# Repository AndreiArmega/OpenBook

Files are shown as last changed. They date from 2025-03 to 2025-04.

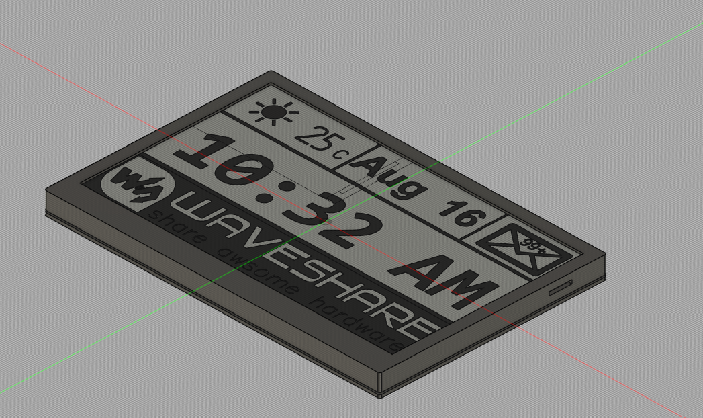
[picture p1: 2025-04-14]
Images/Screenshot 2025-04-14 231651.png

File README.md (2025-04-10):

# OpenBook
## Diagrama bloc
Diagram

## Bill of Materials
| Device | Datasheet | Purchase |
|---|---|---|
| 112A-TAAR-R03_ATTEND | [Datasheet](https://www.attend.com.tw/data/download/file/112A-TAAR-R03_Spec.pdf) | [Purchase](https://www.digikey.be/en/products/detail/attend-technology/112A-TAAR-R03/17633923) |
| ADAFRUIT_LEDCHIP-LED0603 | [Datasheet](https://www.mouser.com/datasheet/2/423/LSM0603472V_(1)-1379786.pdf) | [Purchase](https://grobotronics.com/led-0603-smd-blue.html?sl=en) |
| BD5229G-TR | [Datasheet](https://www.rohm.com/products/power-management/voltage-detectors/adjustable-delay-time/bd5229g-product) | [Purchase](https://eu.mouser.com/ProductDetail/ROHM-Semiconductor/BD5229G-TR?qs=4kLU8WoGk0vvnhrrYwdszw%3D%3D) |
| BUTTON_CUSYOMV1 | [Datasheet](https://www.mouser.com/datasheet/2/315/sw_lt_eng_smalls_side-1289033.pdf) | [Purchase](https://industry.panasonic.com/global/en/products/control/switch/light-touch/number/evqpuj02k) |
| CPH3225A | [Datasheet](https://ro.mouser.com/datasheet/2/360/Seiko_Instruments_MicroBattery_E_20230330_2024Jan_-3561061.pdf) | [Purchase](https://ro.mouser.com/ProductDetail/Seiko-Semiconductors/CPH3225A?qs=3etwrb1wR%252BhUOph6lAO7eg%3D%3D) |
| DS3231SN# | [Datasheet](https://ro.mouser.com/datasheet/2/609/DS3231-3421123.pdf) | [Purchase](https://ro.mouser.com/ProductDetail/Analog-Devices-Maxim-Integrated/DS3231SN?qs=1eQvB6Dk1vhUlr8%2FOrV0Fw%3D%3D) |
| EAGLE-LTSPICE_CC0402 | [Datasheet](https://ro.mouser.com/datasheet/2/447/UPY_GP_NP0_16V_to_50V_18-1730511.pdf) | [Purchase](https://ro.mouser.com/ProductDetail/YAGEO/CC0402CRNPO9BN6R8?qs=AgBp2OyFlx%2FJkIyOSG1YWg%3D%3D) |
| ESP32-WROVER_AVX | [Datasheet](https://www.espressif.com/sites/default/files/documentation/esp32-wrover-e_esp32-wrover-ie_datasheet_en.pdf) | [Purchase](https://www.espressif.com/en/products/modules) |
| ESP32_WROVER_BME680_BME680 | [Datasheet](https://www.bosch-sensortec.com/media/boschsensortec/downloads/datasheets/bst-bme680-ds001.pdf) | [Purchase](https://www.optimusdigital.ro/en/temperature-sensors/4468-adafruit-bme680-temperature-humidity-pressure-and-gas-sensor.html) |
| ESP32_WROVER_EAGLE-LTSPICE_RR0402 | [Datasheet](https://www.espressif.com/sites/default/files/documentation/esp32-wrover-b_datasheet_en.pdf) | [Purchase](https://hr.mouser.com/ProductDetail/Espressif-Systems/ESP32-WROVER-E-N16R8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) |
| ESP32_WROVER_SPARKFUN-DISCRETESEMI_MOSFET_PCH-DMG2305UX-7 | [Datasheet](https://www.diodes.com/assets/Datasheets/DMG2305UX.pdf) | [Purchase](https://ro.mouser.com/ProductDetail/Diodes-Incorporated/DMG2305UX-7?qs=L1DZKBg7t5F%2FNBHrjfxC%252Bg%3D%3D) |
| ESP32_WROVER_SPARKFUN-IC-POWER_MCP73831 | [Datasheet](https://cdn.sparkfun.com/assets/learn_tutorials/6/9/5/MCP738312.pdf) | [Purchase](https://www.amazon.com/SparkFun-MicroMod-Main-Board-Built/dp/B0CD3D1V8J) |
| ESP32-C6-WROOM-1-N8 | [Datasheet](https://www.espressif.com/sites/default/files/documentation/esp32-c6-wroom-1_wroom-1u_datasheet_en.pdf) | [Purchase](https://www.digikey.com/en/products/detail/espressif/ESP32-C6-WROOM/2271115) |
| ESP32C6_VARISTORCN1812 | [Datasheet](https://www.alldatasheet.com/view.jsp?Searchword=CN1812) | [Purchase](https://www.digikey.com/en/products/base-product/epcos-tdk-electronics/495/CN1812/678185) |
| FH34SRJ-24S-0.5SH_99 | [Datasheet](https://ro.mouser.com/datasheet/2/185/FH34SRJ_24S_0_5SH_99__CL0580_1255_6_99_2DDrawing_0-1615044.pdf) | [Purchase](https://www.hirose.com/en/product/global-stock-information/CL0580-1255-6-99) |
| MAX17048G+T10 | [Datasheet](https://eu.mouser.com/datasheet/2/609/MAX17048_MAX17049-3469099.pdf) | [Purchase](https://eu.mouser.com/ProductDetail/Analog-Devices-Maxim-Integrated/MAX17048G+T10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) |
| MBR0530 | [Datasheet](https://eu.mouser.com/datasheet/2/308/MBR0530_D-1810985.pdf) | [Purchase](https://eu.mouser.com/ProductDetail/onsemi-Fairchild/MBR0530?qs=VOMQJJE%252BBNniwJKcE3T43Q%3D%3D) |
| MCP73831 | [Datasheet](https://ww1.microchip.com/downloads/en/DeviceDoc/MCP73831-Family-Data-Sheet-DS20001984H.pdf) | [Purchase](https://www.microchip.com/en-us/product/mcp73831) |
| PGB1010603MR | [Datasheet](https://www.littelfuse.com/assetdocs/pulseguard-esd-suppressors-pgb1-datasheet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) | [Purchase](https://ro.mouser.com/ProductDetail/Littelfuse/PGB1010603MR?qs=gu7KAQ731URLg4GSnNNN7Q%3D%3D) |
| QWIIC_CONNECTORJS-1MM | [Datasheet](https://eu.mouser.com/datasheet/2/813/Qwiic_Connector_Datasheet-1223982.pdf) | [Purchase](https://eu.mouser.com/ProductDetail/SparkFun/PRT-14417?qs=wd5RIQLrsJhgdz%2FpmZ%2F3GQ%3D%3D) |
| RCL_CPOL-EUCT3528 | [Datasheet](https://www.rcl.com/datasheet/CPOL-EUCT3528.pdf) | [Purchase](https://www.rcl.com/purchase/CPOL-EUCT3528) |
| SAMACSYS_PARTS_USB4110-GF-A | [Datasheet](https://ro.mouser.com/datasheet/2/837/GCT_USB4110_Product_Drawing___20k_cycles-3455479.pdf) | [Purchase](https://ro.mouser.com/ProductDetail/GCT/USB4110-GF-A?qs=KUoIvG%2F9IlYiZvIXQjyJeA%3D%3D) |
| SI1308EDL-T1-GE3 | [Datasheet](https://www.vishay.com/docs/63399/si1308edl.pdf) | [Purchase](https://eu.mouser.com/ProductDetail/Vishay-Semiconductors/SI1308EDL-T1-GE3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) |
| Solder Jumper | [Datasheet](https://multimedia.3m.com/mws/media/117314O/3m-bumpon-protective-products-molded-shapes-colored-and-clear.pdf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) | [Purchase](https://www.digikey.ro/ro/products/detail/3m/SJ-5007-BLACK/102599) |
| TPTP20R | [Datasheet ](https://all-industrial-shop.com/catalog/misumi/id1304817_a-tptp20-10-4001-p05-199001) | [Purchase](https://all-industrial-shop.com/catalog/misumi/id1304817_a-tptp20-10-4001-p05-199001) |
| USBLC6-2SC6Y | [Datasheet](https://eu.mouser.com/datasheet/2/389/usblc6_2sc6y-1852505.pdf) | [Purchase](https://eu.mouser.com/ProductDetail/STMicroelectronics/USBLC6-2SC6Y?qs=gNDSiZmRJS%2FOgDexvXkdow%3D%3D)  |
| W25Q512JVEIQ | [Datasheet](https://eu.mouser.com/datasheet/2/949/Winbond_W25Q512JV_Datasheet-3240039.pdf) | [Purchase](https://eu.mouser.com/ProductDetail/Winbond/W25Q512JVEIQ?qs=l7cgNqFNU1jw6svr3at6tA%3D%3D) |
| XC6220A331MR-G | [Datasheet](https://eu.mouser.com/datasheet/2/760/xc6220-3371556.pdf) | [Purchase](https://eu.mouser.com/ProductDetail/Torex-Semiconductor/XC6220A331MR-G?qs=AsjdqWjXhJ8ZSWznL1J0gg%3D%3D) |

## Functionality
### ESP32-C6-WROOM-1-N8
The ESP32-C6-WROOM-1-N8 is a powerful microcontroller module from Espressif Systems that integrates Wi-Fi (802.11ax) and Bluetooth LE (5.0) capabilities. It is designed for IoT (Internet of Things) applications that require wireless communication. Let's focus on how the components interact with this microcontroller, as well as consider interfaces, communication specifications, energy consumption, and processing:

### Key Components That Interact with the ESP32-C6-WROOM-1-N8:
  1. MCP73831 - Battery Charge Management IC
  Interface: This component connects to the ESP32-C6 via GPIO pins to monitor battery status and control the charging process.
  
  Functionality: The MCP73831 manages the charging of lithium-ion batteries. It interacts with the ESP32 for real-time battery monitoring. The ESP32 can detect charging states or battery levels through ADC (Analog-to-Digital Converter) readings or dedicated communication (e.g., I2C/SPI) if the design includes more advanced battery management.
  
  Power Consumption: The ESP32-C6-WROOM-1-N8 would use this component to ensure efficient power management, especially when operating on a battery.
  
  2. ESP32-WROVER (e.g., ESP32-WROVER-BME680) - Environmental Sensing
  Interface: The ESP32 connects to the BME680 sensor via I2C (or SPI) to read environmental data, such as temperature, humidity, pressure, and air quality.
  
  Functionality: The BME680 sensor communicates with the ESP32 via I2C/SPI, providing critical environmental data. This is commonly used in IoT applications like smart home systems, weather stations, or air quality monitoring systems.
  
  Power Consumption: The ESP32-C6 must manage the power consumption of the sensor and optimize wake-up intervals, using low-power states when idle.
  
  3. USBLC6-2SC6Y - USB Transient Voltage Suppressor
  Interface: This component is generally used on the USB lines connecting the ESP32 to external devices. It is connected across the USB data lines to prevent damage from voltage spikes.
  
  Functionality: It ensures that the USB port of the ESP32 is protected from over-voltage or transient spikes that could otherwise damage sensitive circuits.
  
  Power Consumption: USBLC6-2SC6Y does not significantly affect power consumption, but it ensures stable power delivery to the microcontroller.
  
  4. DS3231SN# - Real-Time Clock (RTC)
  Interface: I2C is used to connect the DS3231SN# RTC module with the ESP32.
  
  Functionality: The DS3231 provides accurate timekeeping, even when the ESP32 is powered down. This is important for time-dependent tasks, like logging data, scheduling actions, or maintaining time in low-power states.
  
  Power Consumption: The ESP32 can operate in deep sleep mode, while the DS3231 keeps track of time. The RTC has low power consumption and runs off a small coin cell battery.
  
  5. W25Q512JVEIQ - Flash Memory
  Interface: This flash memory connects to the ESP32 via the SPI interface.
  
  Functionality: The W25Q512JVEIQ is used to store data, firmware, or other assets for the application. It is commonly used for data logging, firmware updates, or storing non-volatile data.
  
  Power Consumption: Flash memory is typically low power, but the ESP32 should manage read/write operations carefully to conserve energy, especially when operating on battery power.
  
  6. PGB1010603MR - ESD Protection
  Interface: This component is placed on various I/O lines of the ESP32 (such as GPIO, SPI, I2C, etc.) to protect against electrostatic discharge.
  
  Functionality: PGB1010603MR protects the ESP32 from ESD, preventing damage from static electricity that could occur during handling or operation.
  
  Power Consumption: It does not impact the power consumption of the ESP32, but it is crucial for ensuring stable operation in environments with potential ESD risk.

### Communication Interfaces & Specifications:
Wireless Communication: The ESP32-C6-WROOM-1-N8 supports Wi-Fi 6 (802.11ax) and Bluetooth 5.0. These are high-speed communication protocols for connecting to IoT devices, networks, and other wireless systems.

Wi-Fi: 2.4GHz and 5GHz bands support high-speed data transfer.

Bluetooth LE: Allows for low-power, short-range communication with peripherals.

Wired Communication: The microcontroller supports multiple communication protocols, such as:

SPI: Used for high-speed communication with peripherals like flash memory (W25Q512JVEIQ).

I2C: A popular protocol for sensors like the BME680 and the DS3231.

UART: For serial communication, commonly used for debugging or communication with external devices.

### Processing Power & Energy Consumption:
  Processing: The ESP32-C6 has a single-core 32-bit RISC-V processor with a clock speed of up to 160 MHz. It is optimized for real-time processing and is capable of handling multi-tasking and communication protocols like Wi-Fi and Bluetooth simultaneously.
  
  Energy Consumption: The ESP32-C6-WROOM-1-N8 is designed for low-power applications. It features various low-power modes such as:
  
  Light Sleep: Keeps the Wi-Fi/Bluetooth active while reducing CPU activity.
  
  Deep Sleep: Cuts off most peripherals and uses minimal power.
  
  Hibernation: The lowest power mode, where only the RTC is active (useful for low-power sensors or battery-powered IoT devices).
  
  Power Management: When integrated with components like the MCP73831 for battery charging and the DS3231SN# RTC, the ESP32-C6 can be configured to wake up at specific intervals to process tasks (e.g., checking sensors, reporting data) and return to sleep mode to conserve battery life.

## ESP32-C6 Pins

| **Pin ESP32** | **Funcție Principală** | **Componentă Conectată / Scop** |
|---|---|---|
| IO0 | INT_RTC | U3 (DNS323, Interrupt from RTC) – Triggering or controlling RTC operations. |
| IO1 | 32KHZ | U3 (DNS323, 32kHz Crystal Oscillator) – Used for timing and clock generation. |
| IO2 | MISO | J4 (112A-TAAR) & U1 (W25Q, SPI Data In) – Master In Slave Out line for SPI communication. |
| IO3 | EPD_BUSY | J1 (FH34, EPD busy signal) – Indicates when the EPD is busy. |
| IO4 | SS_SD | J4 (112A-TAAR, SD card chip select) – Controls SD card communication. |
| IO5 | EPD_DC | J1 (FH34, EPD Data/Command signal) – Controls the data or command mode for the EPD. |
| IO6 | SPI SCK | J1 (FH34) & U1 (W25Q, SPI Clock) – Provides clock signal for SPI communication. |
| IO7 | SPI MOSI | J4 (112A-TAAR), J1 (FH34), U1 (W25Q, SPI Data Out) – Master Out Slave In line for SPI communication. |
| IO8 | GPIO8 | 3V3 – Used as a general-purpose I/O pin, connected to 3.3V for simple logic. |
| IO9 | IO/BOOT | IC1 (BD5229) – Used for bootloading during startup. |
| IO10 | GPIO / SPI EPD CS | J1 (FH34, EPD Chip Select) – Selects EPD for SPI communication. |
| IO11 | GPIO / SPI FLASH CS | U1 (W25Q, Flash Chip Select) – Selects the flash memory for SPI communication. |
| IO12 | USB D | D1 (USBLC6, USB Data -) – Handles negative signal of USB communication. |
| IO13 | USB D+ | D1 (USBLC6, USB Data +) – Handles positive signal of USB communication. |
| IO15 | I/O CHANGE | IC1 (BD5229) – Used for triggering I/O state changes or controlling other circuits. |
| GPIO16 | TX | SPI TX – Transmit data via SPI for various components. |
| GPIO17 | RX | SPI RX – Receive data via SPI for various components. |
| IO18 | RTC_RST | U3 (DNS323, RTC Reset) – Reset signal for RTC operations. |
| IO19 | I2C SDA | IC2 (MCP73831, RTC SDA), IC3 (BME680, BME SDA/SDO) – I2C data line. |
| IO20 | EPD_3V3_c | Q2 (Voltage regulator) – Provides 3.3V to the EPD. |
| IO21 | SDA | J3 (Qwiic Connector), U3 (DNS323), BME680 (Sensor SDA), U4 (Max17048, SDA) – I2C data line for communication. |
| IO22 | SCL | J3 (Qwiic Connector), U3 (DNS323), BME680 (Sensor SCL), U4 (Max17048, SCL) – I2C clock line for communication. |
| IO23 | EPD_RST | J1 (FH34, EPD Reset) – Resets the EPD during initialization. |
| EN | RESET | Pull-up to 3.3V – Used to reset the ESP32-C6 module. |
| VDD | 3V3 | 3.3V Power supply for the module. |
| GND | GND | Ground connection. |
| NC | - | Not connected – Reserved pin. |

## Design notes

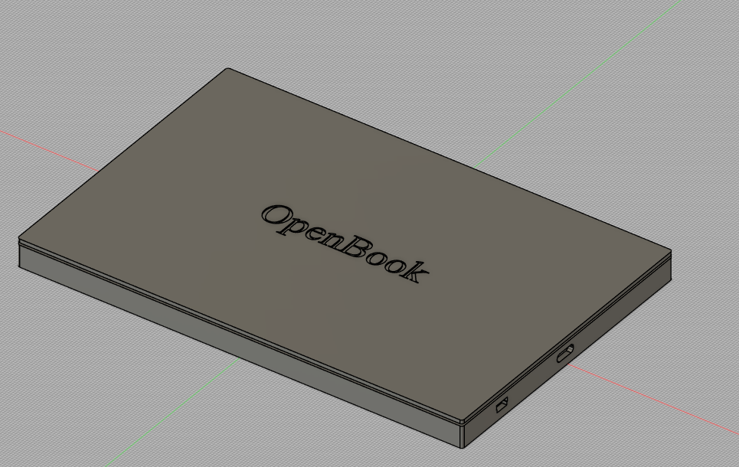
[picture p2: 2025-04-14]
Images/Screenshot 2025-04-14 231531.png

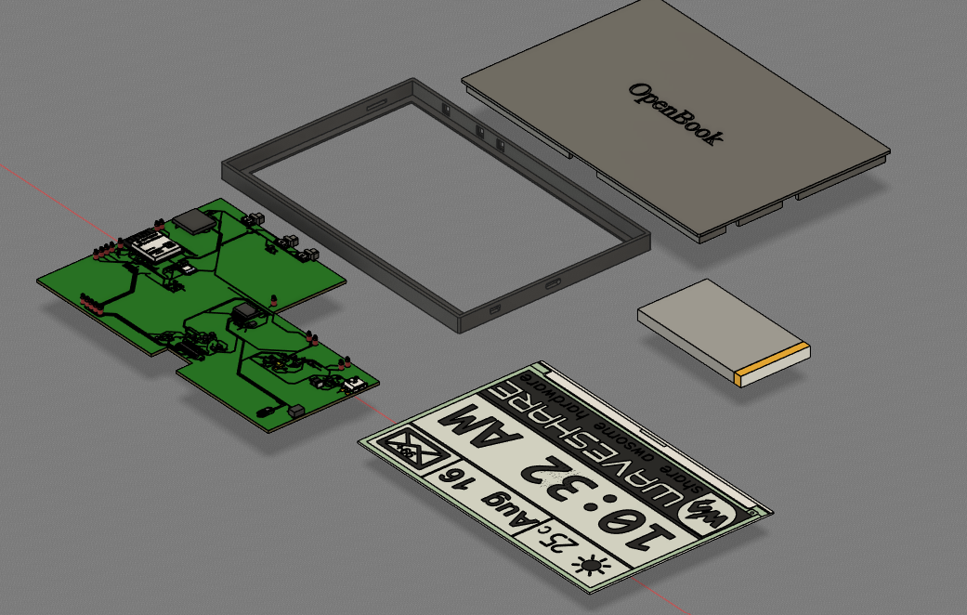
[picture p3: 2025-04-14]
Images/Screenshot 2025-04-14 232221.png

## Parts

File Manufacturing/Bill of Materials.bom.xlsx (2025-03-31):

Qty | Value | Device | Package | Parts | Description | ARROW_PART_NUMBER | ARROW_PRICE-STOCK | AVAILABILITY | CENTROID_NOT_SPECIFIED | CHECK_PRICES | COPYRIGHT | DATASHEET | DESCRIPTION | DIGIKEY_DESCRIPTION | DIGIKEY_PART_NUMBER | HEIGHT | LEAD_FREE | MANUFACTURER_NAME | MANUFACTURER_PART_NUMBER | MF | MFR_NAME | MOUSER_PART_NUMBER | MOUSER_PRICE-STOCK | MOUSER_TESTING_PART_NUMBER | MOUSER_TESTING_PRICE-STOCK | MP | MPN | PACKAGE | POPULARITY | PREFIX | PRICE | PROD_ID | PURCHASE-URL | ROHS | SNAPEDA_LINK | SPICEMODEL | SPICEPREFIX | TEMPERATURE_RANGE_HIGH | TEMPERATURE_RANGE_LOW | TP_SIGNAL_NAME | VALUE
1 |  | ADAFRUIT_LEDCHIP-LED0603 | ADAFRUIT_CHIP-LED0603 | CHG_LED | LED
1 |  | SJ | SJ | SJ1 | SMD solder JUMPER |  |  |  |  |  |  |  |  |  |  |  |  |  |  |  |  |  |  |  |  |  |  |  | 3
1 | 0.1uF/50V | ESP32_WROVER_EAGLE-LTSPICE_CC0402 | ESP32_WROVER_EAGLE-LTSPICE_C0402 | EPD_C5 | CAPACITOR, European symbol |  |  |  |  |  |  |  |  |  |  |  |  |  |  |  |  |  |  |  |  |  |  |  |  |  |  |  |  |  |  | NONE | C
1 | 0.47 | ESP32_WROVER_EAGLE-LTSPICE_RR0402 | ESP32_WROVER_EAGLE-LTSPICE_R0402 | R3 | RESISTOR, European symbol |  |  |  |  |  |  |  |  |  |  |  |  |  |  |  |  |  |  |  |  |  |  |  |  |  |  |  |  |  |  | NONE | R
1 | 100k | ESP32_WROVER_EAGLE-LTSPICE_RR0402 | ESP32_WROVER_EAGLE-LTSPICE_R0402 | R1_PWRUSB | RESISTOR, European symbol |  |  |  |  |  |  |  |  |  |  |  |  |  |  |  |  |  |  |  |  |  |  |  |  |  |  |  |  |  |  | NONE | R
5 | 100nF | EAGLE-LTSPICE_CC0402 | ESP32_WROVER_EAGLE-LTSPICE_C0402 | C6, C8, C9, C10, C_DELAY | CAPACITOR, European symbol |  |  |  |  |  |  |  |  |  |  |  |  |  |  |  |  |  |  |  |  |  |  |  |  |  |  |  |  |  |  | NONE | C
3 | 100nF | ESP32_WROVER_EAGLE-LTSPICE_CC0402 | ESP32_WROVER_EAGLE-LTSPICE_C0402 | C1, C2, C4_USB | CAPACITOR, European symbol |  |  |  |  |  |  |  |  |  |  |  |  |  |  |  |  |  |  |  |  |  |  |  |  |  |  |  |  |  |  | NONE | C
1 | 100uF | RCL_CPOL-EUCT3528 | RCL_CT3528 | C3 | POLARIZED CAPACITOR, European symbol |  |  |  |  |  |  |  |  |  |  |  |  |  |  |  |  |  |  |  |  |  |  |  | 0 |  |  |  |  |  |  |  | C
1 | 10K | ESP32_WROVER_EAGLE-LTSPICE_RR0402 | ESP32_WROVER_EAGLE-LTSPICE_R0402 | R_CL1 | RESISTOR, European symbol |  |  |  |  |  |  |  |  |  |  |  |  |  |  |  |  |  |  |  |  |  |  |  |  |  |  |  |  |  |  | NONE | R
15 | 10k | ESP32_WROVER_EAGLE-LTSPICE_RR0402 | ESP32_WROVER_EAGLE-LTSPICE_R0402 | R1, R1_PINH, R1_PINH1, R2-PINH, R2-PINH1, R4, R5, R6, R7, R8, R9, R10, R_BOOT, R_CHANGE, R_RESET | RESISTOR, European symbol |  |  |  |  |  |  |  |  |  |  |  |  |  |  |  |  |  |  |  |  |  |  |  |  |  |  |  |  |  |  | NONE | R
1 | 10uF | ESP32_WROVER_EAGLE-LTSPICE_CC0402 | ESP32_WROVER_EAGLE-LTSPICE_C0402 | C7 | CAPACITOR, European symbol |  |  |  |  |  |  |  |  |  |  |  |  |  |  |  |  |  |  |  |  |  |  |  |  |  |  |  |  |  |  | NONE | C
1 | 112A-TAAR-R03_ATTEND | 112A-TAAR-R03_ATTEND | 112ATAARR03ATTEND | J4 | Micro SD Card Socket, Push-Push Type, Top Mount, SMT, H=1.83mm, 10u |  |  |  |  |  |  |  | Micro SD Card Socket | Push-Push Type | Top Mount | SMT | H=1.83mm | 10u |  |  | 1.9mm |  | ATTEND | 112A-TAAR-R03 ATTEND
1 | 15 | ESP32_WROVER_EAGLE-LTSPICE_RR0402 | ESP32_WROVER_EAGLE-LTSPICE_R0402 | R_CAPACITOR | RESISTOR, European symbol |  |  |  |  |  |  |  |  |  |  |  |  |  |  |  |  |  |  |  |  |  |  |  |  |  |  |  |  |  |  | NONE | R
1 | 1uF | EAGLE-LTSPICE_CC0402 | ESP32_WROVER_EAGLE-LTSPICE_C0402 | C5 | CAPACITOR, European symbol |  |  |  |  |  |  |  |  |  |  |  |  |  |  |  |  |  |  |  |  |  |  |  |  |  |  |  |  |  |  | NONE | C
9 | 1uF/50V | ESP32_WROVER_EAGLE-LTSPICE_CC0402 | ESP32_WROVER_EAGLE-LTSPICE_C0402 | EPD_C1, EPD_C2, EPD_C6, EPD_C7, EPD_C8, EPD_C9, EPD_C10, EPD_C11, EPD_C12 | CAPACITOR, European symbol |  |  |  |  |  |  |  |  |  |  |  |  |  |  |  |  |  |  |  |  |  |  |  |  |  |  |  |  |  |  | NONE | C
1 | 2.2 | ESP32_WROVER_EAGLE-LTSPICE_RR0402 | ESP32_WROVER_EAGLE-LTSPICE_R0402 | R2 | RESISTOR, European symbol |  |  |  |  |  |  |  |  |  |  |  |  |  |  |  |  |  |  |  |  |  |  |  |  |  |  |  |  |  |  | NONE | R
1 | 200 | ESP32_WROVER_EAGLE-LTSPICE_RR0402 | ESP32_WROVER_EAGLE-LTSPICE_R0402 | R1_BAT | RESISTOR, European symbol |  |  |  |  |  |  |  |  |  |  |  |  |  |  |  |  |  |  |  |  |  |  |  |  |  |  |  |  |  |  | NONE | R
2 | 20V/4.2A/52mO/1.4W | ESP32_WROVER_SPARKFUN-DISCRETESEMI_MOSFET_PCH-DMG2305UX-7 | ESP32_WROVER_SPARKFUN-DISCRETESEMI_SOT23-3 | Q1, Q2 | P-channel MOSFETs |  |  |  |  |  |  |  |  |  |  |  |  |  |  |  |  |  |  |  |  |  |  |  |  |  |  | TRAN-14388 |  |  |  |  |  |  |  |  | 20V/4.2A/52mO/1.4W
1 | 2k | ESP32_WROVER_EAGLE-LTSPICE_RR0402 | ESP32_WROVER_EAGLE-LTSPICE_R0402 | R2_BAT | RESISTOR, European symbol |  |  |  |  |  |  |  |  |  |  |  |  |  |  |  |  |  |  |  |  |  |  |  |  |  |  |  |  |  |  | NONE | R
5 | 4.7uF | ESP32_WROVER_EAGLE-LTSPICE_CC0402 | ESP32_WROVER_EAGLE-LTSPICE_C0402 | C1_BAT, C1_BAT1, C1_BAT2, C2_BAT, C5_USB | CAPACITOR, European symbol |  |  |  |  |  |  |  |  |  |  |  |  |  |  |  |  |  |  |  |  |  |  |  |  |  |  |  |  |  |  | NONE | C
1 | 4.7uF/25V | ESP32_WROVER_EAGLE-LTSPICE_CC0402 | ESP32_WROVER_EAGLE-LTSPICE_C0402 | C4 | CAPACITOR, European symbol |  |  |  |  |  |  |  |  |  |  |  |  |  |  |  |  |  |  |  |  |  |  |  |  |  |  |  |  |  |  | NONE | C
2 | 5k1 | ESP32_WROVER_EAGLE-LTSPICE_RR0402 | ESP32_WROVER_EAGLE-LTSPICE_R0402 | R2-USB, R2-USB1 | RESISTOR, European symbol |  |  |  |  |  |  |  |  |  |  |  |  |  |  |  |  |  |  |  |  |  |  |  |  |  |  |  |  |  |  | NONE | R
1 | 68uH | 744043680IND_4828-WE-TPC_WRE | IND_4828-WE-TPC_WRE | L1 |  |  |  |  |  |  | Copyright (C) 2024 Ultra Librarian. All rights reserved. |  |  |  |  |  |  |  | 744043680 |  | Wurth Electronics
1 | BD5229G-TR | BD5229G-TR | SOT95P280X125-5N | IC1 | Voltage Detector with Adjustable Delay Time: CMOS processes are utilized to develop high precision, low current consumption CMOS reset ICs that allow arbitrary setting of the delay time. The extensive lineup includes both Nch Open Drain and CMOS output types in a wide range of detection voltages (from 2.3V to 6.0V, in 0.1V steps), enabling selection of the ideal solution based on customer requirements. In addition, the entire series is of course both lead-free and RoHS-compliant. |  |  |  |  |  |  |  | Voltage Detector with Adjustable Delay Time: CMOS processes are utilized to develop high precision | low current consumption CMOS reset ICs that allow arbitrary setting of the delay time. The extensive lineup includes both Nch Open Drain and CMOS output types in a wide range of detection voltages (from 2.3V to 6.0V | in 0.1V steps) | enabling selection of the ideal solution based on customer requirements. In addition | the entire series is of course both lead-free and RoHS-compliant. |  |  | 1.25mm |  | ROHM Semiconductor | BD5229G-TR |  |  | 755-BD5229G-TR | https://www.mouser.co.uk/ProductDetail/ROHM-Semiconductor/BD5229G-TR?qs=4kLU8WoGk0vvnhrrYwdszw%3D%3D
3 | BUTTON_CUSYOMV1 | BUTTON_CUSYOMV1 | MYBUTTON | BUT1, BUT2, BUT3
1 | CPH3225A | CPH3225A | CAPCP3225X100N | C10_SUPERCAP | Cap 0.011F 3.3V 1210 Flat Check availability |  |  | Not in stock |  | https://www.snapeda.com/parts/CPH3225A/Seiko+Instruments/view-part/?ref=eda |  |  | 11 mF (EDLC) Supercapacitor 3.3 V 1210 (3225 Metric) - - |  |  |  |  |  |  | Seiko Instruments |  |  |  |  |  | CPH3225A |  | 1210 Seiko |  |  | None |  | https://www.snapeda.com/api/url_track_click_mouser/?unipart_id=562593&manufacturer=Seiko Instruments&part_name=CPH3225A&search_term=None |  | https://www.snapeda.com/parts/CPH3225A/Seiko+Instruments/view-part/?ref=snap
1 | DS3231SN# | DS3231SN# | SOIC127P1032X265-16N | U3 | Real Time Clock Serial 16-Pin SOIC W T/R Check availability |  |  | In Stock |  | https://www.snapeda.com/parts/DS3231SN%23/Analog+Devices/view-part/?ref=eda |  |  | Extremely Accurate I²C-Integrated RTC/TCXO/Crystal |  |  |  |  |  |  | Analog Devices |  |  |  |  |  | DS3231SN# |  | SOIC-16 Maxim |  |  | None |  | https://www.snapeda.com/api/url_track_click_mouser/?unipart_id=99048&manufacturer=Analog Devices&part_name=DS3231SN#&search_term=None |  | https://www.snapeda.com/parts/DS3231SN%23/Analog+Devices/view-part/?ref=snap
1 | ESP32-C6-WROOM-1-N8 | ESP32-C6-WROOM-1-N8 | XCVR_ESP32-C6-WROOM-1-N8 | U2 | Check availability |  |  | In Stock |  | https://www.snapeda.com/parts/ESP32-C6-WROOM-1-N8/Espressif+Systems/view-part/?ref=eda |  |  | Multiprotocol Modules ESP32-C6 module | Wi-Fi 6 in 2.4 GHz band | Bluetooth 5 | Zigbee 3.0 and Thread. ESP34-WROOM Compatible - ENGINEERING SAMPLE |  |  |  |  |  |  | Espressif Systems |  |  |  |  |  | ESP32-C6-WROOM-1-N8 |  | None |  |  | None |  |  |  | https://www.snapeda.com/parts/ESP32-C6-WROOM-1-N8/Espressif+Systems/view-part/?ref=snap
1 | ESP32C6_VARISTORCN1812 | ESP32C6_VARISTORCN1812 | ESP32C6_VARISTOR_CT/CN1812 | PFMF.050.1 | VARISTOR |  |  |  |  |  |  |  |  |  |  |  |  |  |  |  |  |  |  |  |  |  |  |  | 0
2 | ESP32_WROVER_AVX---SD0805S020S1R0_AVX_SD0805S020S1R0_0_0AVX_SD0805S020S1R0_0_0 | ESP32_WROVER_AVX---SD0805S020S1R0_AVX_SD0805S020S1R0_0_0AVX_SD0805S020S1R0_0_0 | ESP32_WROVER_AVX---SD0805S020S1R0_AVX_SD0805S020S1R0_0 | D2, D7 | Schottky Barrier Rectifier Diode |  |  |  | No |  |  | http://datasheets.avx.com/schottky.pdf |  | DIODE SCHOTTKY 20V 1A 0805 | 478-7800-1-ND |  | yes |  |  | AVX |  | 581-SD0805S020S1R0 |  |  |  |  |  | 0805 (2012 metric) |  | D |  |  |  | yes |  |  |  | +125°C | -55°C
1 | ESP32_WROVER_BME680_BME680 | ESP32_WROVER_BME680_BME680 | ESP32_WROVER_BME680_PSON80P300X300X100-8N | SENSOR2 | Integrated Environmental Unit |  |  | Unavailable |  |  |  |  | Integrated Environmental Unit |  |  |  |  |  |  | Bosch Sensortec |  |  |  |  |  | BME680 |  | LGA-8 Bosch Tools |  |  | None
1 | ESP32_WROVER_SPARKFUN-IC-POWER_MCP73831 | ESP32_WROVER_SPARKFUN-IC-POWER_MCP73831 | ESP32_WROVER_SPARKFUN-IC-POWER_SOT23-5 | MCP73831 | MCP73831T Li-Ion, Li-Pol Controller |  |  |  |  |  |  |  |  |  |  |  |  |  |  |  |  |  |  |  |  |  |  |  |  |  |  | IC-09995
1 | FH34SRJ-24S-0.5SH_99_ | FH34SRJ-24S-0.5SH_99_ | FH34SRJ24S05SH99 | J1 | (0.50mm) Surface Mount, Right Angle |  |  |  |  |  |  |  | 24 Position FFC | FPC Connector Contacts | (0.50mm) Surface Mount | Right Angle |  |  | 1.1mm |  | Hirose | FH34SRJ-24S-0.5SH(99) |  |  | 798-FH34SRJ24S05SH99 | https://www.mouser.co.uk/ProductDetail/Hirose-Connector/FH34SRJ-24S-0.5SH99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
1 | MAX17048G+T10 | MAX17048G+T10 | SON50P200X200X80-9N | U4 | Check availability |  |  | In Stock |  | https://www.snapeda.com/parts/MAX17048G+T10/Analog+Devices/view-part/?ref=eda |  |  | 3µA 1-Cell/2-Cell Fuel Gauge with ModelGauge |  |  |  |  |  |  | Analog Devices |  |  |  |  |  | MAX17048G+T10 |  | TDFN-8 Maxim |  |  | None |  | https://www.snapeda.com/api/url_track_click_mouser/?unipart_id=329239&manufacturer=Analog Devices&part_name=MAX17048G+T10&search_term=None |  | https://www.snapeda.com/parts/MAX17048G+T10/Analog+Devices/view-part/?ref=snap
3 | MBR0530 | MBR0530 | SOD3716X135N | D3, D4, D5 | ON SEMICONDUCTOR - MBR0530 - DIODE, SCHOTTKY, 0.5A, 30V, SOD-123 |  |  | In Stock |  | https://www.snapeda.com/parts/MBR0530/Onsemi/view-part/?ref=eda |  |  | Diode Schottky 30 V 500mA Surface Mount SOD-123 |  |  |  |  |  |  | ON Semiconductor |  |  |  |  |  | MBR0530 |  | SOD-123-2 ON Semiconductor |  |  | None |  | https://www.snapeda.com/api/url_track_click_mouser/?unipart_id=179458&manufacturer=ON Semiconductor&part_name=MBR0530&search_term=None |  | https://www.snapeda.com/parts/MBR0530/Onsemi/view-part/?ref=snap
6 | PGB1010603MR | PGB1010603MR | DIOC1608X36N | D6, D8, D9, D10, D11, D12 | Check availability |  |  | In Stock |  | https://www.snapeda.com/parts/PGB1010603MR/Littelfuse/view-part/?ref=eda |  |  | 150V (Typ) Clamp - Ipp Tvs Diode Surface Mount 0603 (1608 Metric) |  |  |  |  |  |  | Littelfuse Inc. |  |  |  |  |  | PGB1010603MR |  | 0603 Littelfuse Inc. |  |  | None |  | https://www.snapeda.com/api/url_track_click_mouser/?unipart_id=5659453&manufacturer=Littelfuse Inc.&part_name=PGB1010603MR&search_term=None |  | https://www.snapeda.com/parts/PGB1010603MR/Littelfuse/view-part/?ref=snap
1 | QWIIC_RIGHT_ANGLE | QWIIC_CONNECTORJS-1MM | JST04_1MM_RA | J3 | SparkFun I2C Standard Qwiic Connector |  |  |  |  |  |  |  |  |  |  |  |  |  |  |  |  |  |  |  |  |  |  |  |  |  |  | CONN-13694 |  |  |  |  |  |  |  |  | QWIIC_RIGHT_ANGLE
1 | SAMACSYS_PARTS_USB4110-GF-A | SAMACSYS_PARTS_USB4110-GF-A | SAMACSYS_PARTS_USB4110GFA | J2 | CONN USB 2.0 TYPE-C R/A SMT |  |  |  |  |  |  |  | CONN USB 2.0 TYPE-C R/A SMT |  |  | 3.26mm |  | GCT (GLOBAL CONNECTOR TECHNOLOGY) | USB4110-GF-A |  |  | 640-USB4110-GF-A | https://www.mouser.co.uk/ProductDetail/GCT/USB4110-GF-A?qs=KUoIvG%2F9IlYiZvIXQjyJeA%3D%3D
1 | SI1308EDL-T1-GE3 | SI1308EDL-T1-GE3 | SOT65P210X110-3N | Q3 | MOSFET N-Ch 30V 1.5A TrenchFET SC70 Vishay Si1308EDL-T1-GE3 N-channel MOSFET Transistor, 1.5 A, 30 V, 3-Pin SC-70 |  |  | In Stock |  | https://www.snapeda.com/parts/SI1308EDL-T1-GE3/Vishay+Siliconix/view-part/?ref=eda |  |  | Si1308EDL-T1-GE3 N-channel MOSFET Transistor | 1.5 A | 30 V | 3-Pin SC-70 | Siliconix / Vishay SI1308EDL-T1-GE3 |  |  |  |  |  |  | Vishay Siliconix |  |  |  |  |  | SI1308EDL-T1-GE3 |  | SOT-323 Vishay Semiconductor |  |  | None |  | https://www.snapeda.com/api/url_track_click_mouser/?unipart_id=274603&manufacturer=Vishay Siliconix&part_name=SI1308EDL-T1-GE3&search_term=None |  | https://www.snapeda.com/parts/SI1308EDL-T1-GE3/Vishay+Siliconix/view-part/?ref=snap
17 | TPTP20R | TPTP20R | TP20R | TP1, TP2, TP3, TP4, TP5, TP6, TP7, TP8, TP9, TP10, TP11, TP12, TP13, TP14, TP15, TP16, TP17 | Test pad |  |  |  |  |  |  |  |  |  |  |  |  |  |  |  |  |  |  |  |  |  |  |  | 2
1 | USBLC6-2SC6Y | USBLC6-2SC6Y | SOT95P280X145-6N | D1 | Low Cap. ESD Protection Auto SOT-23-6 STMicroelectronics USBLC6-2SC6Y, Dual Uni-Directional TVS Diode Array, 6-Pin SOT-23 |  |  | In Stock |  | https://www.snapeda.com/parts/USBLC6-2SC6Y/STMicroelectronics/view-part/?ref=eda |  |  | 17V Clamp 5A (8/20µs) Ipp Tvs Diode Surface Mount SOT-23-6 |  |  |  |  |  |  | STMicroelectronics |  |  |  |  |  | USBLC6-2SC6Y |  | SOT-23-6 STMicroelectronics |  |  | None |  |  |  | https://www.snapeda.com/parts/USBLC6-2SC6Y/STMicroelectronics/view-part/?ref=snap
1 | W25Q512JVEIQ | W25Q512JVEIQ | SON127P600X800X80-9N | U1 | Check availability |  |  | In Stock |  | https://www.snapeda.com/parts/W25Q512JVEIQ/Winbond+Electronics/view-part/?ref=eda |  |  | FLASH - NOR Memory IC 512Mb (64M x 8) SPI - Quad I/O 133 MHz 8-WSON (8x6) |  |  |  |  |  |  | Winbond Electronics |  |  |  |  |  | W25Q512JVEIQ |  | Package |  |  | None |  |  |  | https://www.snapeda.com/parts/W25Q512JVEIQ/Winbond+Electronics/view-part/?ref=snap
1 | XC6220A331MR-G | XC6220A331MR-G | SOT95P280X120-5N | IC4 | LDO Voltage Regulators |  |  |  |  |  |  |  | LDO Voltage Regulators |  |  | 1.2mm |  | Torex | XC6220A331MR-G |  |  | 865-XC6220A331MR-G | https://www.mouser.co.uk/ProductDetail/Torex-Semiconductor/XC6220A331MR-G?qs=AsjdqWjXhJ8ZSWznL1J0gg%3D%3D

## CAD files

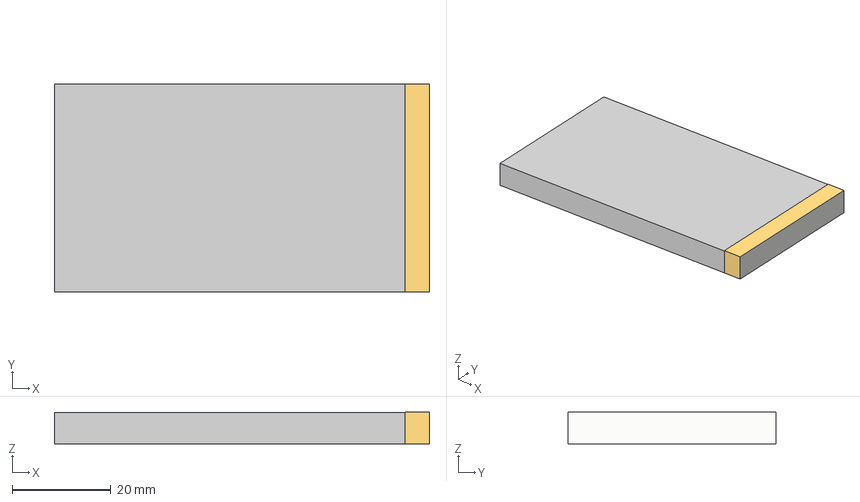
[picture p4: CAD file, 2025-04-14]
Hardware/LP584174 v1.step
75.9 x 42.0 x 6.40 mm

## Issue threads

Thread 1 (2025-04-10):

Create project folder structure

Robert2003, 2025-04-10:
Set up the structure mentioned in the project's specification:

  - Hardware
  |-- fișierul schematic (.sch)
  |-- fișierul cu board-ul (.brd)
  - Manufacturing
  |-- gerbers.zip
  |-- fișierul Bill of Materials (.bom)
  |-- fișierul Pick and Place (.cpl)
  - Mechanical
  |-- fișierul 3D cu dispozitivul complet (PCB + baterie + display + carcasa) - exploded view (.step)
  |-- fișierul 3D Fusion360 cu dispozitivul complet
  - Images
  |-- imagini cu randări ale dispozitivului, plăcii etc.
  - LICENSE
  - README.md

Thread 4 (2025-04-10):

[PCB] Measures are on the wrong layer

Robert2003, 2025-04-10:
Measures should not be on <b>Top</b> layer. Use <b>Measures (Layer 47)</b> instead.

Closed 2025-04-14.

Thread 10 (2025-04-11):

[PCB] Power wires are too wide

Robert2003, 2025-04-11:
Your power wires are <b>0.3048 mm</b> instead of <b>0.3 mm</b>

Closed 2025-04-14.

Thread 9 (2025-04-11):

[3D] Test Pad model is too large

Robert2003, 2025-04-11:
TP model is larger than the case. My recommendation is to create a custom cylinder 3D model.

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

Closed 2025-04-14.
